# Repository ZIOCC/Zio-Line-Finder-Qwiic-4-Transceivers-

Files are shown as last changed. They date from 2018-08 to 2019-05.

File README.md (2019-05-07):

# Zio Line Finder (Qwiic 4 Transceivers)

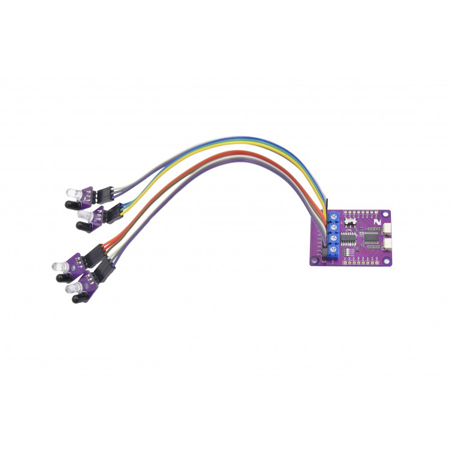
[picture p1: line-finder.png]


> This product can be available for purchase [here](https://www.smart-prototyping.com/Zio-Line-Finder-Qwiic-4-Transceivers).

#### Description
This is a Qwiic I2C version of a line-following sensor array, intended especially for building robots that take advantage of I2C for communication between subsystems.

Like other line-following sensor modules, it has four IR reflectance-sensing sub-modules that can detect a line’s position. We use a PCA9539A I/O expander to detect when a given sub-module’s output voltage crosses its logic-level threshold, indicating the detection of the line. If one of the sub-module I/O channels is driven LOW, that’s where the line is.

There are four potentiometers to independently adjust the IR modules’ sensitivities to suit different robot platforms, accounting for differences in sensor mounting heights. There are four LEDs that provide a visual indicator for the detection status of each channel, which makes it easy to tune the sensitivity of each sensor channel.
Because the PCA9539A has 16 digital I/O channels, we’ve broken out the other 12 channels to standard-pitch pin-headers so you can take advantage of them as you see fit.

#### Specification

* Four Channel IR Sensors
* I2C sensor: PCA9539A
* I2C address:0x74-0x77 (Default:0x74)
* Differential Comparator IC: LM339DR
* Extra Digital Sensor Channel: 12 Channels
* Dimension: 47.2x 36.5mm
* Weight: Main board: 7.4g, IR sensor board: 0.9g

#### Links

* [Eagle File and Schematic](https://github.com/ZIOCC/Zio-Line-Finder-Qwiic-4-Transceivers-)
* [PCA9539 Library and Example Code](https://www.smart-prototyping.com/image/data/NOA-RnD/101904%20line%20finder/Zio_Line_Finder_Library.zip)
* [PCA9539 Datasheet](http://www.ti.com/lit/ds/symlink/pca9539.pdf)
* [LM339DR Datasheet](http://www.ti.com/lit/ds/snosbj3e/snosbj3e.pdf)

> ###### About Zio
> Zio is a new line of open sourced, compact, and grid layout boards, fully integrated for Arduino and Qwiic ecosystem. Designed ideally for wearables, robotics, small-space limitations or other on the go projects. Check out other awesome Zio products [here](https://www.smart-prototyping.com/Zio).

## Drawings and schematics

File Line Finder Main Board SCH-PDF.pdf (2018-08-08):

1 | 2 | 3 | 4 | 5 | 6

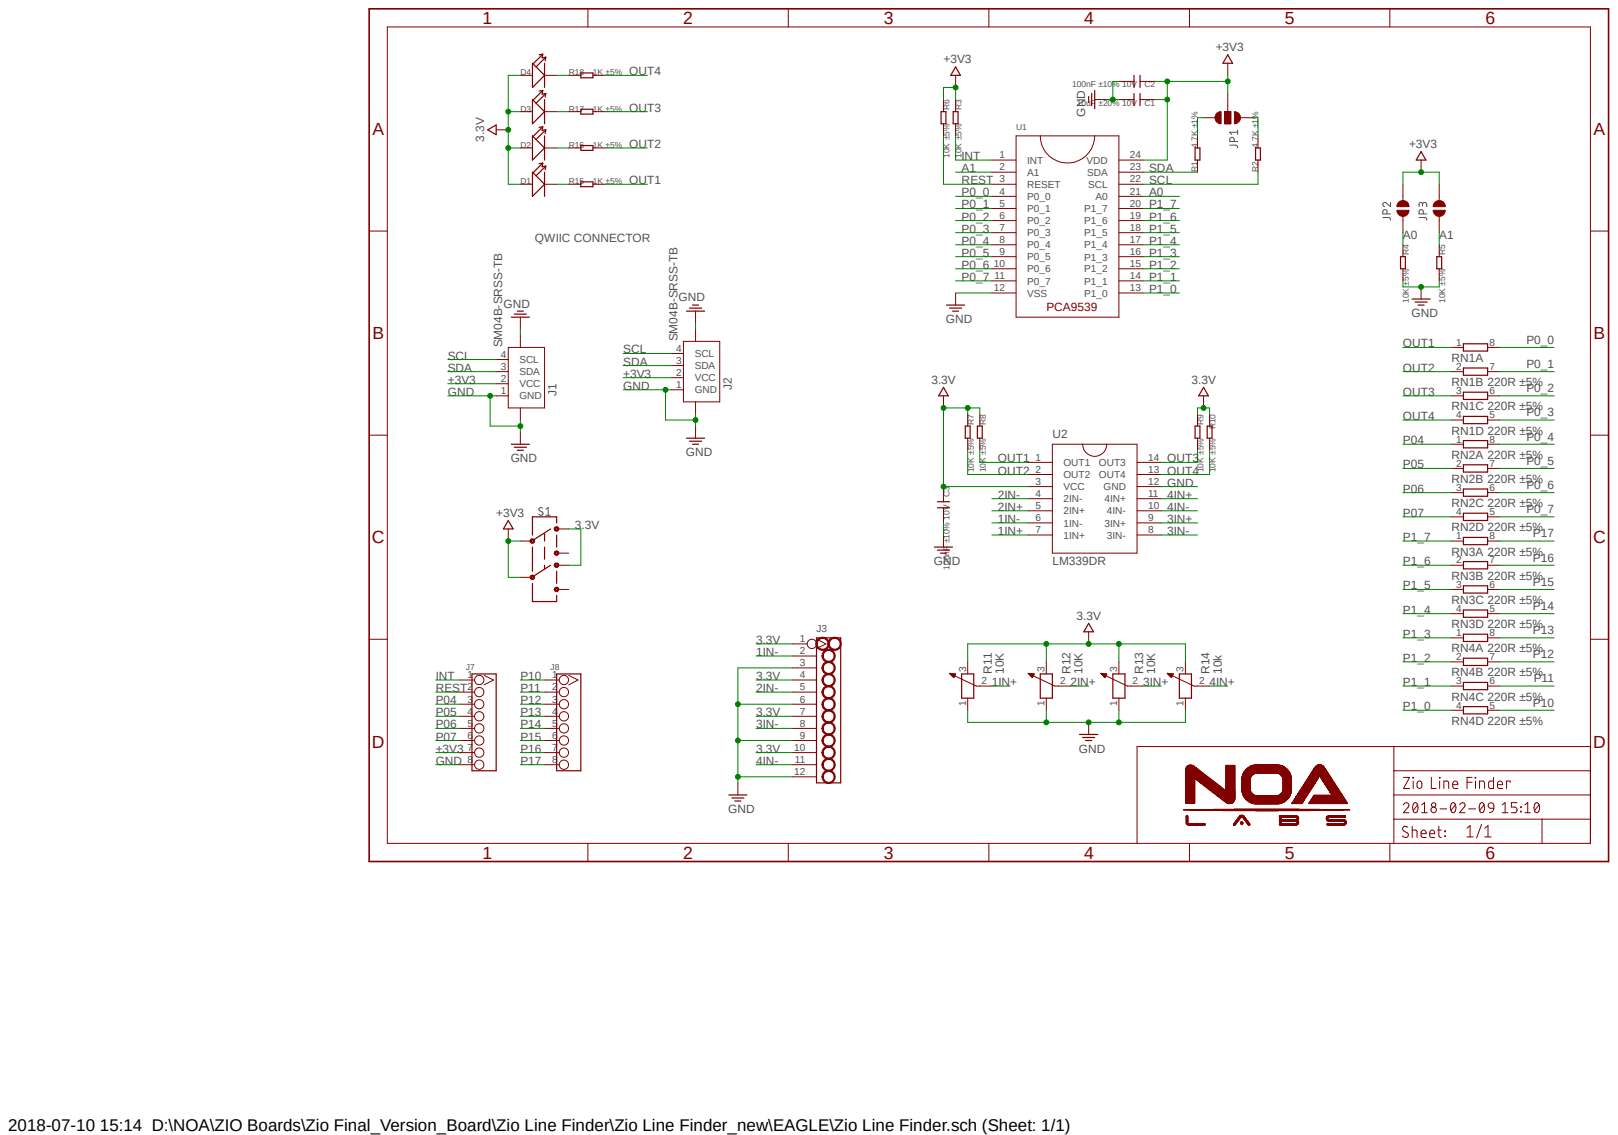
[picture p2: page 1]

2018-07-10 15:14 D:\NOA\ZIO Boards\Zio Final_Version_Board\Zio Line Finder\Zio Line Finder_new\EAGLE\Zio Line Finder.sch (Sheet: 1/1)

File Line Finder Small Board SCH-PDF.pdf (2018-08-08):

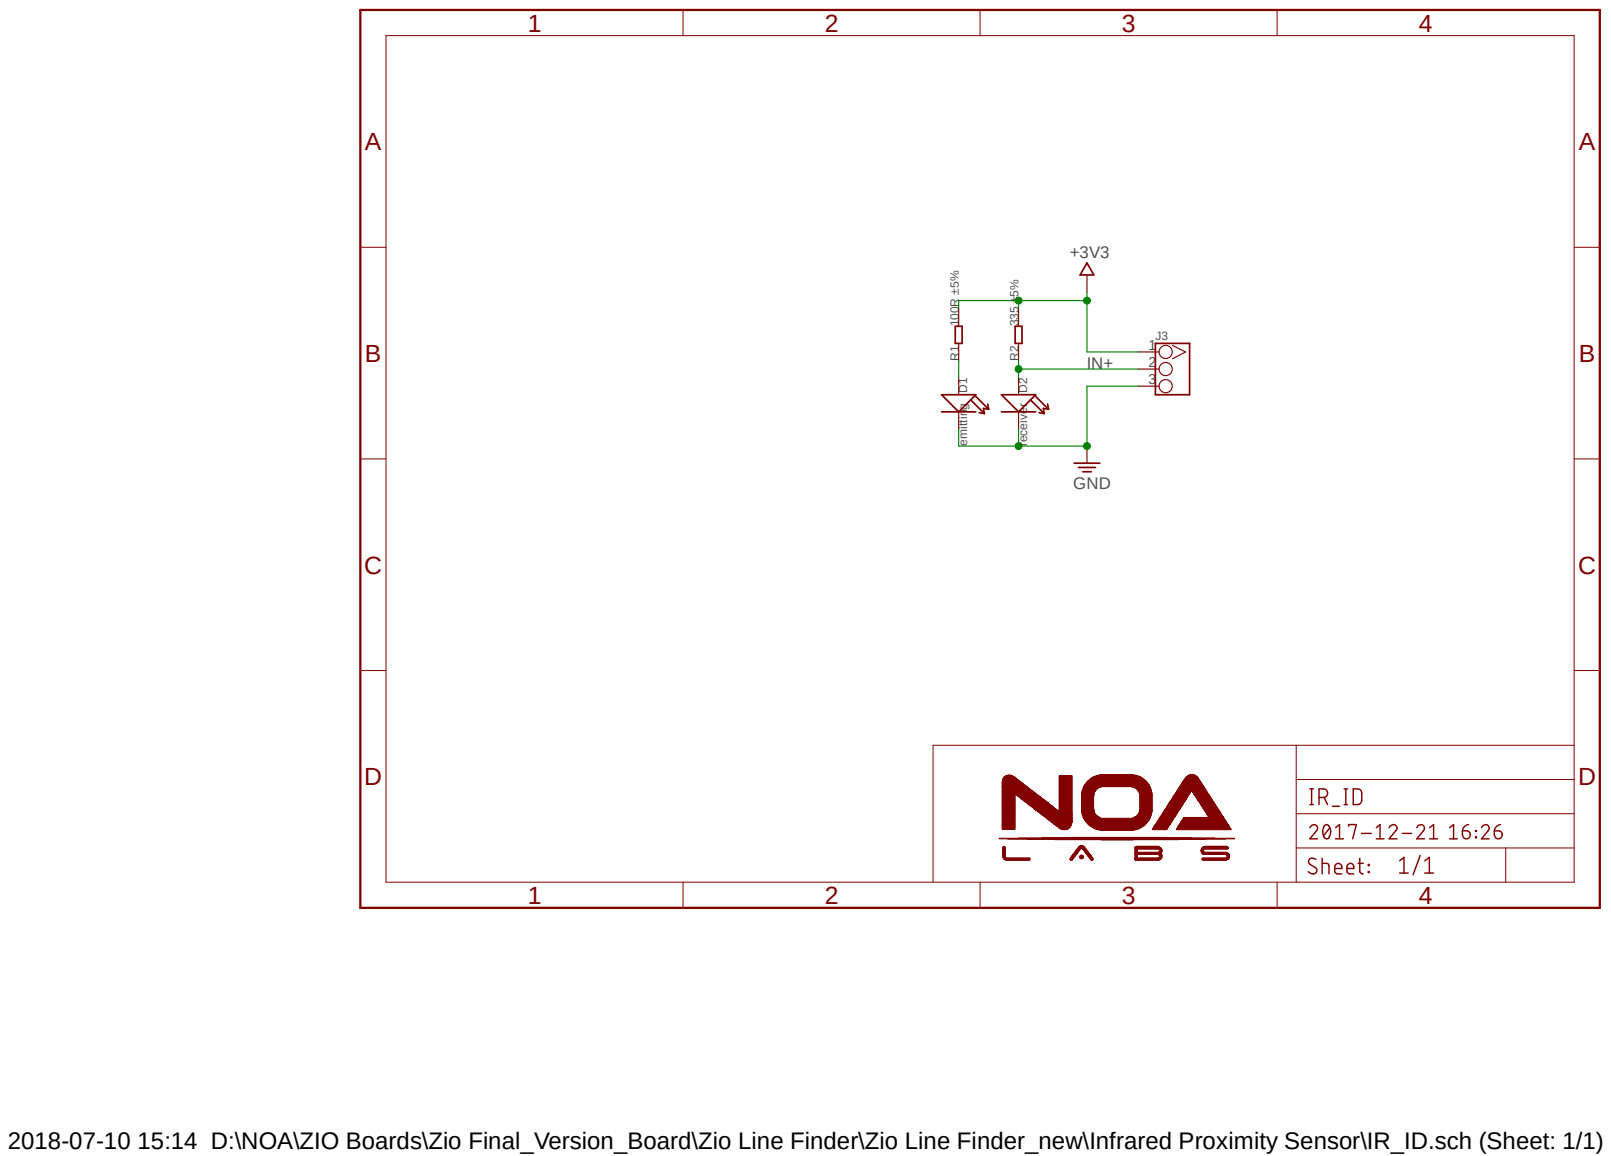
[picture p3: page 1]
GND ¹⁰⁰R ±5%; 335 ±5% emitting; receiver

2018-07-10 15:14 D:\NOA\ZIO Boards\Zio Final_Version_Board\Zio Line Finder\Zio Line Finder_new\Infrared Proximity Sensor\IR_ID.sch (Sheet: 1/1)

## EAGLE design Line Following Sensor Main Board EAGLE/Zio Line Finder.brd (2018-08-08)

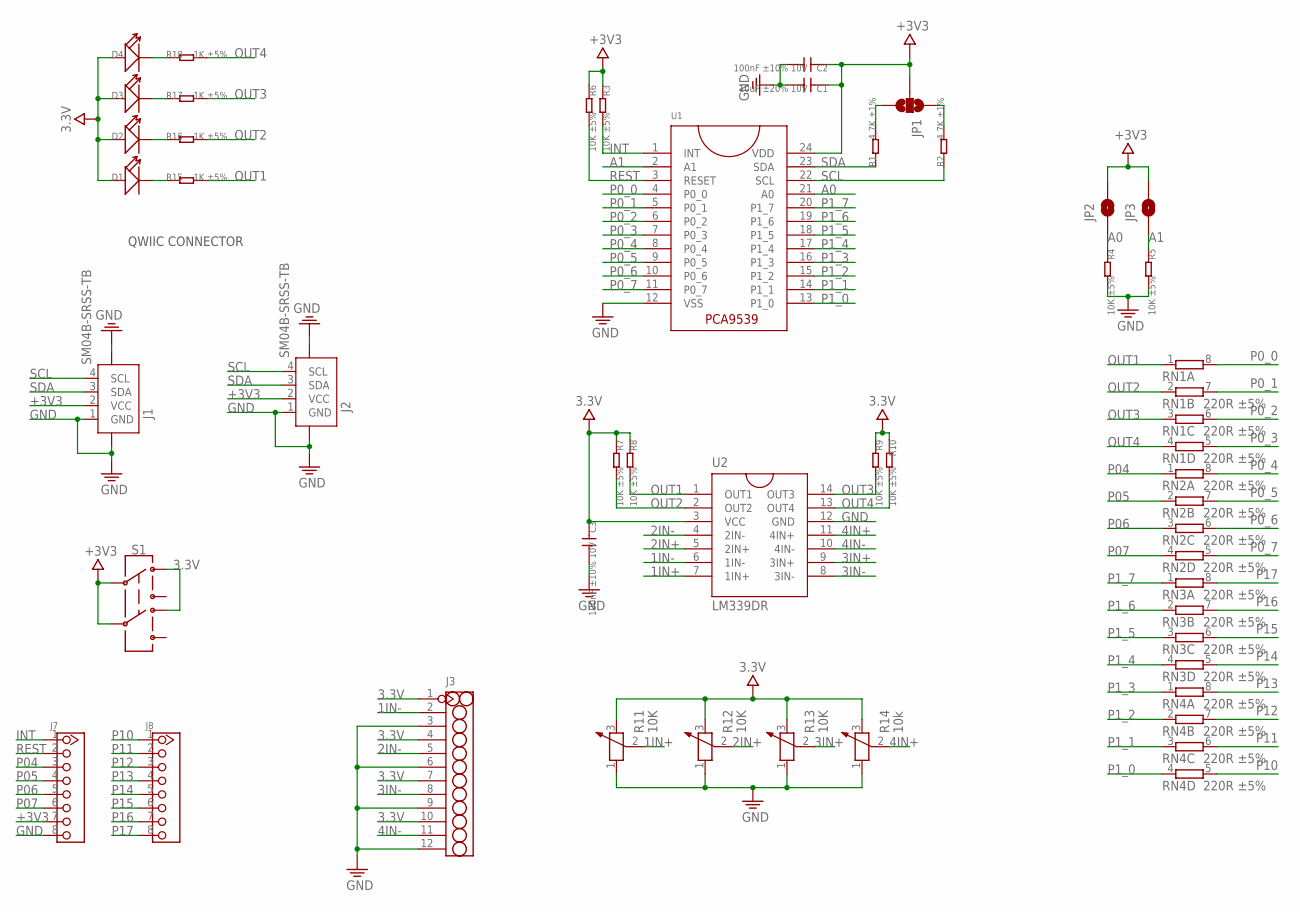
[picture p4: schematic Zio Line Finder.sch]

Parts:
C1: 10uF ±20% 10V; 0603
C2, C3: 100nF ±10% 10V; 0603
D1, D2, D3, D4: LED'0603'; LED-0603
J1, J2: SM04B-SRSS-TB; JST-SH-4P
J3: HEADER-12P-2.54; 12P-2.54
J7, J8: HEADER-8P-60/35MIL; 8P-2.54-60/35MIL
JP1: JUMPER-SMT_3_2-NC_PASTE_NOCREM; SMT-JUMPER_3_2-NC_PASTE_SILK_NOCREM
JP2, JP3: JUMPER-SMT_2_NC_PASTE_NOCREM; SMT-JUMPER_2_NC_PASTE_SILK_NOCREM
R1, R2: 4.7K ±1%; 0402
R3, R4, R5, R6, R7, R8, R9, R10: 10K ±5%; 0402
R11, R12, R13: 10K; 3P-SQUA-7X6.8
R14: 10k; 3P-SQUA-7X6.8
R15, R16, R17, R18: 1K ±5%; 0402
RN1, RN2, RN3, RN4: 220R ±5%; RESISTOR-DIL_0603-ARV
S1: SWITCH-DPDT-SMD-AYZ0202; SWITCH_DPDT_SMD_AYZ0202
U1: PCA9539; TSSOP24
U2: LM339DR; SOIC14-8.7

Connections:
1IN+: R11.2, U2.7 (1IN+)
1IN-: J3.2, U2.6 (1IN-)
2IN+: R12.2, U2.5 (2IN+)
2IN-: J3.5, U2.4 (2IN-)
3.3V: C3.1, D1.+, D2.+, D3.+, D4.+, J3.1, J3.4, J3.7, J3.10, R7.1, R8.1, R9.1, R10.1, R11.3, R12.3, R13.3, R14.3, S1.1, S1.4, U2.3 (VCC)
3IN+: R13.2, U2.9 (3IN+)
3IN-: J3.8, U2.8 (3IN-)
4IN+: R14.2, U2.11 (4IN+)
4IN-: J3.11, U2.10 (4IN-)
+3V3: C1.1, C2.1, J1.2 (VCC), J2.2 (VCC), J7.7, JP1.2, JP2.2, JP3.2, R3.1, R6.1, S1.2, S1.5, U1.24 (VDD)
A0: JP2.1, R4.1, U1.21 (A0)
A1: JP3.1, R5.1, U1.2 (A1)
GND: C1.2, C2.2, C3.2, J1.1 (GND), J1.NC1 (5), J1.NC2 (6), J2.1 (GND), J2.NC1 (5), J2.NC2 (6), J3.3, J3.6, J3.9, J3.12, J7.8, R4.2, R5.2, R11.1, R12.1, R13.1, R14.1, U1.12 (VSS), U2.12 (GND)
INT: J7.1, R3.2, U1.1 (INT)
unnamed: D1.-, R15.1
unnamed: D2.-, R16.1
unnamed: D3.-, R17.1
unnamed: D4.-, R18.1
unnamed: JP1.3, R1.2
unnamed: JP1.1, R2.2
OUT1: R8.2, R15.2, RN1.1, U2.1 (OUT1)
OUT2: R7.2, R16.2, RN1.2 (1), U2.2 (OUT2)
OUT3: R9.2, R17.2, RN1.3 (1), U2.14 (OUT3)
OUT4: R10.2, R18.2, RN1.4 (1), U2.13 (OUT4)
P0_0: RN1.8 (2), U1.4 (P0_0)
P0_1: RN1.7 (2), U1.5 (P0_1)
P0_2: RN1.6 (2), U1.6 (P0_2)
P0_3: RN1.5 (2), U1.7 (P0_3)
P0_4: RN2.8 (2), U1.8 (P0_4)
P0_5: RN2.7 (2), U1.9 (P0_5)
P0_6: RN2.6 (2), U1.10 (P0_6)
P0_7: RN2.5 (2), U1.11 (P0_7)
P1_0: RN4.4 (1), U1.13 (P1_0)
P1_1: RN4.3 (1), U1.14 (P1_1)
P1_2: RN4.2 (1), U1.15 (P1_2)
P1_3: RN4.1, U1.16 (P1_3)
P1_4: RN3.4 (1), U1.17 (P1_4)
P1_5: RN3.3 (1), U1.18 (P1_5)
P1_6: RN3.2 (1), U1.19 (P1_6)
P1_7: RN3.1, U1.20 (P1_7)
P04: J7.3, RN2.1
P05: J7.4, RN2.2 (1)
P06: J7.5, RN2.3 (1)
P07: J7.6, RN2.4 (1)
P10: J8.1, RN4.5 (2)
P11: J8.2, RN4.6 (2)
P12: J8.3, RN4.7 (2)
P13: J8.4, RN4.8 (2)
P14: J8.5, RN3.5 (2)
P15: J8.6, RN3.6 (2)
P16: J8.7, RN3.7 (2)
P17: J8.8, RN3.8 (2)
REST: J7.2, R6.2, U1.3 (RESET)
SCL: J1.4 (SCL), J2.4 (SCL), R2.1, U1.22 (SCL)
SDA: J1.3 (SDA), J2.3 (SDA), R1.1, U1.23 (SDA)

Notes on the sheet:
QWIIC CONNECTOR

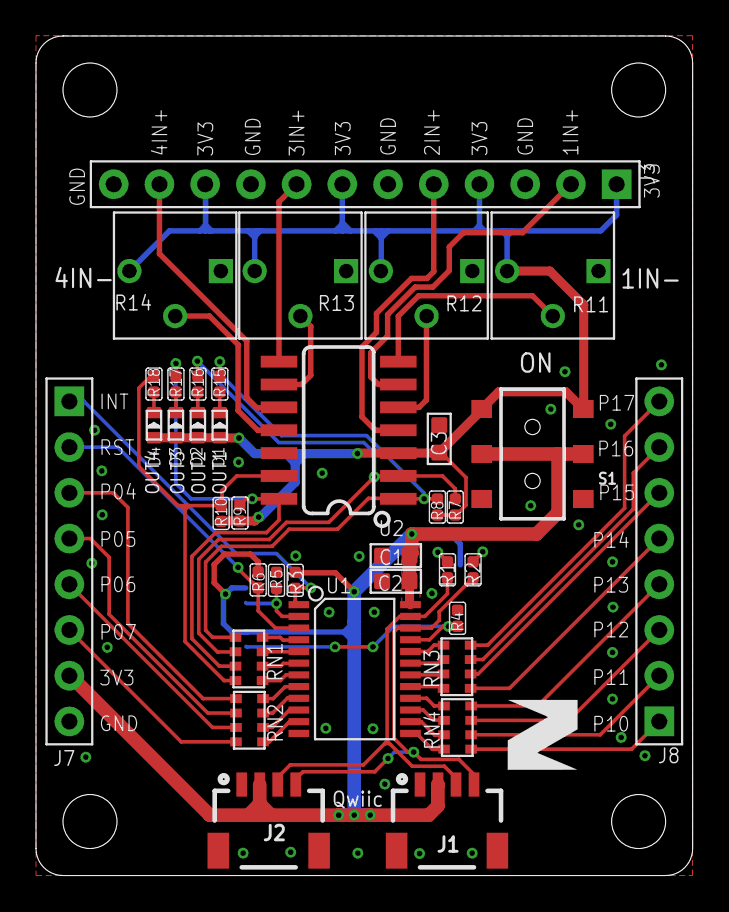
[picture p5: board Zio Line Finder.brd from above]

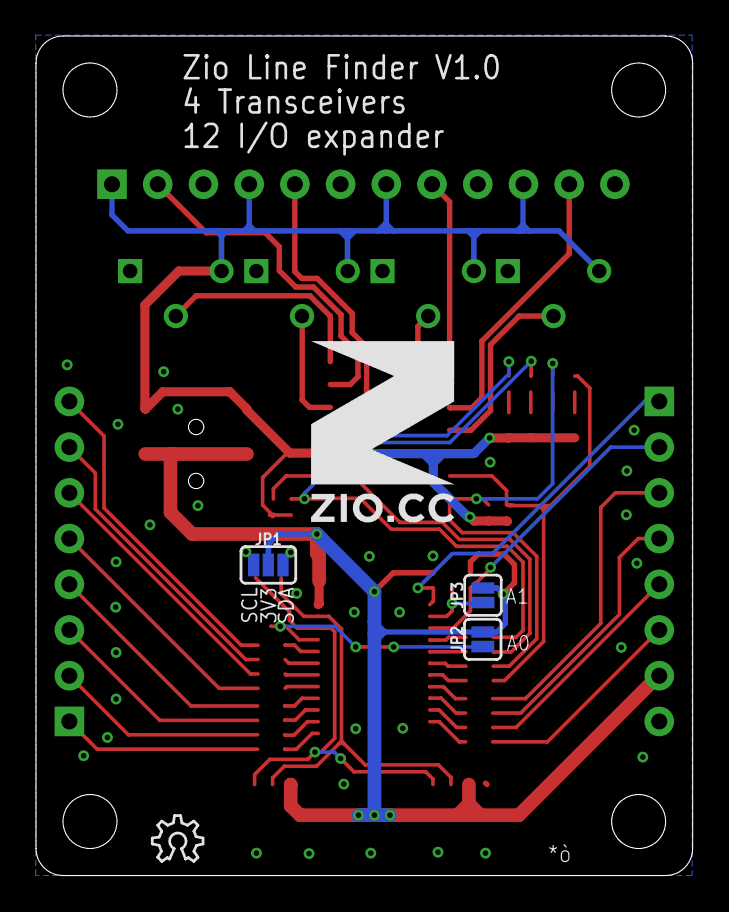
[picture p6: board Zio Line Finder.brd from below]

Board: 2 copper layers, 36.5 x 46.6 mm, 43 parts (5 on the bottom side), 55 nets.

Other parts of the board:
U$6: 10MM
U$7: OSHW_6X100_NOTEXT
U$8: 6MM

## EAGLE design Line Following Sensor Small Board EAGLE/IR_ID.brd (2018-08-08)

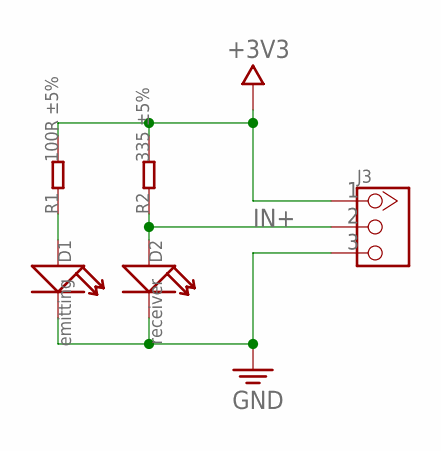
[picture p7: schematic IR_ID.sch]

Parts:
D1: emitting; LED-2P-2.54-6MM
D2: receiver; LED-2P-2.54-6MM
J3: HEADER-3P-2.54; 3P-2.54
R1: 100R ±5%; 0402
R2: 335 ±5%; 0402

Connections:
+3V3: J3.1, R1.2, R2.2
GND: D1.-, D2.-, J3.3
IN+: D2.+, J3.2, R2.1
unnamed: D1.+, R1.1

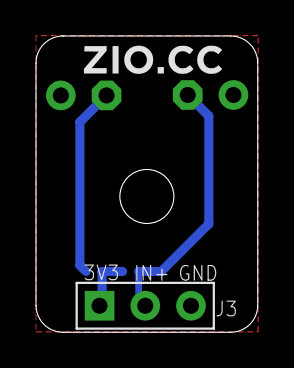
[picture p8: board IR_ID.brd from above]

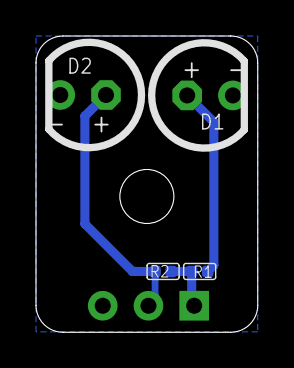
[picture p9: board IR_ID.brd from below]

Board: 2 copper layers, 12.3 x 16.5 mm, 6 parts (4 on the bottom side), 4 nets.

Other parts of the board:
U$1: 1.5MM

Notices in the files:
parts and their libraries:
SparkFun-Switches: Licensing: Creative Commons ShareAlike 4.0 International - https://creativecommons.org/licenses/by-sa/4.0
